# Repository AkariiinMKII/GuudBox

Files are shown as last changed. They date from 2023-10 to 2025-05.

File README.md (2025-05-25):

# GuudBox

GuudBox uses GP2040-CE firmware with custom key maps and layouts, here's related links you may need:

[GP2040-CE GitHub page](https://github.com/OpenStickCommunity/GP2040-CE) | [GP2040-CE documentation](https://gp2040-ce.info/introduction)

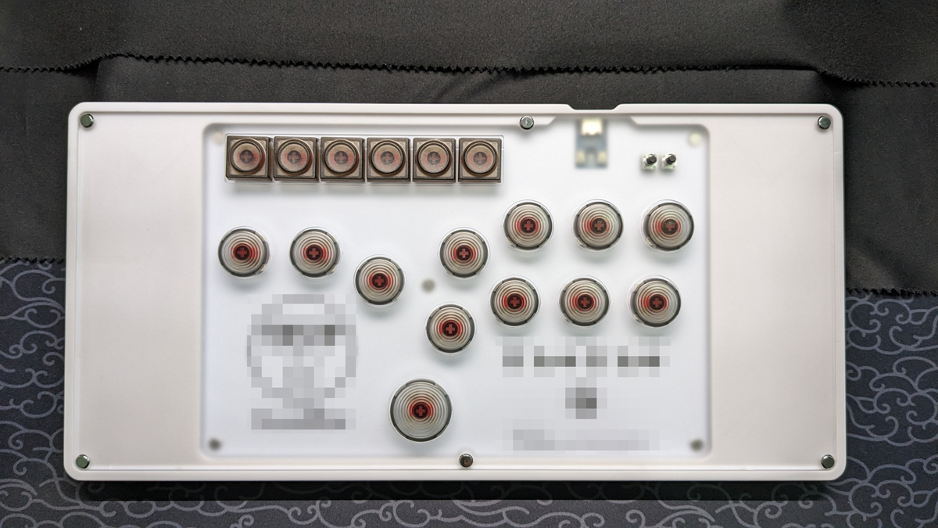
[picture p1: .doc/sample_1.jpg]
Sample

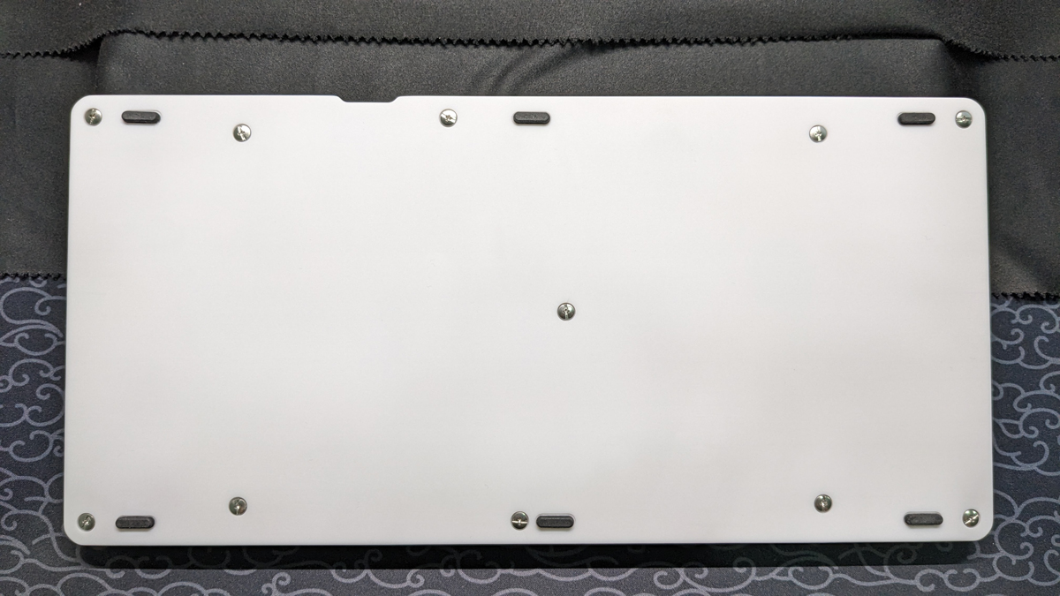
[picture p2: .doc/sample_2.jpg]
Sample

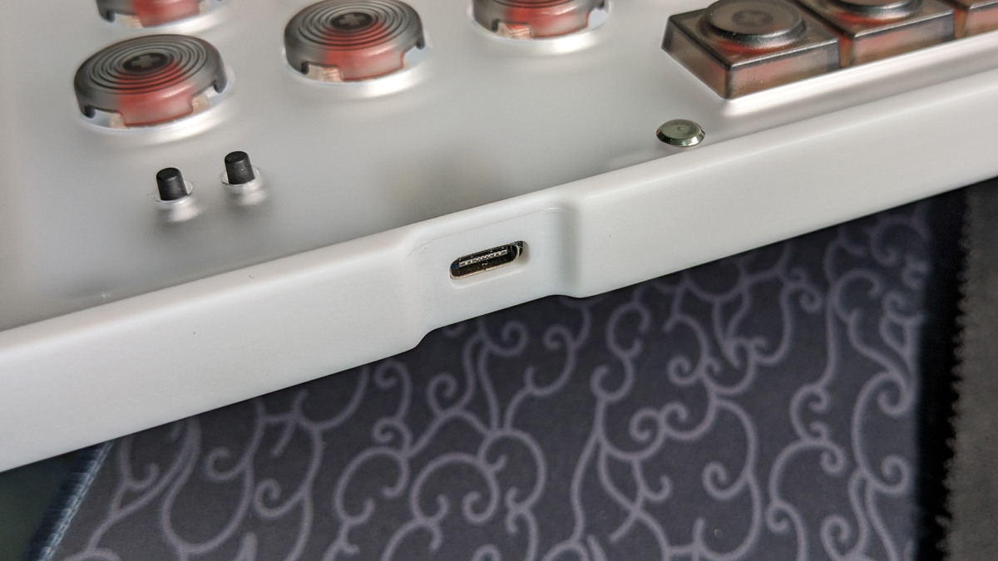
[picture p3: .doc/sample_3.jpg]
Sample


## Hardwares

__Screwdrivers and soldering iron are necessary to build this device!__

__Screwdrivers and soldering iron are necessary to build this device!__

__Screwdrivers and soldering iron are necessary to build this device!__

### Standard parts

_Parts you need to purchase. All of these should be available in China Mainland._

__Make sure you can get these parts (or compatible ones) before building!__

| Parts | Quantity | Shopping links for reference |
| --- | --- | --- |
| Waveshare RP2040-Zero | 1 | |
| Gateron low profile switches v2.0 | 18 | |
| Gateron low profile hotswap connectors  | 18 | |
| 21mm MX switch compatible round keycaps | 12 | [PUNK WORKSHOP](https://item.taobao.com/item.htm?id=684778888971) |
| 26mm MX switch compatible round keycaps | 1 | [PUNK WORKSHOP](https://item.taobao.com/item.htm?id=684778888971) |
| Standard MX switch keycaps | 6 | [DEADLINE DOYS](https://item.taobao.com/item.htm?id=705145796401) |
| 6x6x10mm push button switches | 2 | [LCSC](https://item.szlcsc.com/580446.html) |
| M3*13 locking screws | 6 | [Taobao](https://detail.tmall.com/item.htm?id=714800474141) |
| M3*5 locking screws | 5 | [Taobao](https://detail.tmall.com/item.htm?id=714800474141) |
| 13x4mm round head silicone foot pads* | 6 | [Taobao](https://item.taobao.com/item.htm?id=579251575258) |

_*: Thickness should be greater than 0.5mm._

### Custom parts

| Parts | Quantity | Related files | Remarks |
| --- | --- | --- | --- |
| Controller PCB | 1 | [Gerber_GuudBox.zip](PCB/Gerber_GuudBox.zip) | 1.6mm thick |
| CNC / 3D printed bottom case | 1 | [Bottom Case.STEP (for CNC)](Case/Bottom%20Case.STEP) / [Bottom Case.STL (for 3D printing)](Case/Bottom%20Case.STL) | |
| CNC / laser cutted cover plate* | 1 | [Cover Plate.STEP (for CNC)](Case/Cover%20Plate.STEP) / [Cover Plate.dxf (for laser cutting)](Case/Cover%20Plate.dxf) | 3mm thick |

_*: If you'd like to replace 21mm round keycaps with 26mm ones, use files in [Alternative](/Case/Alternative) folder for cover plate._

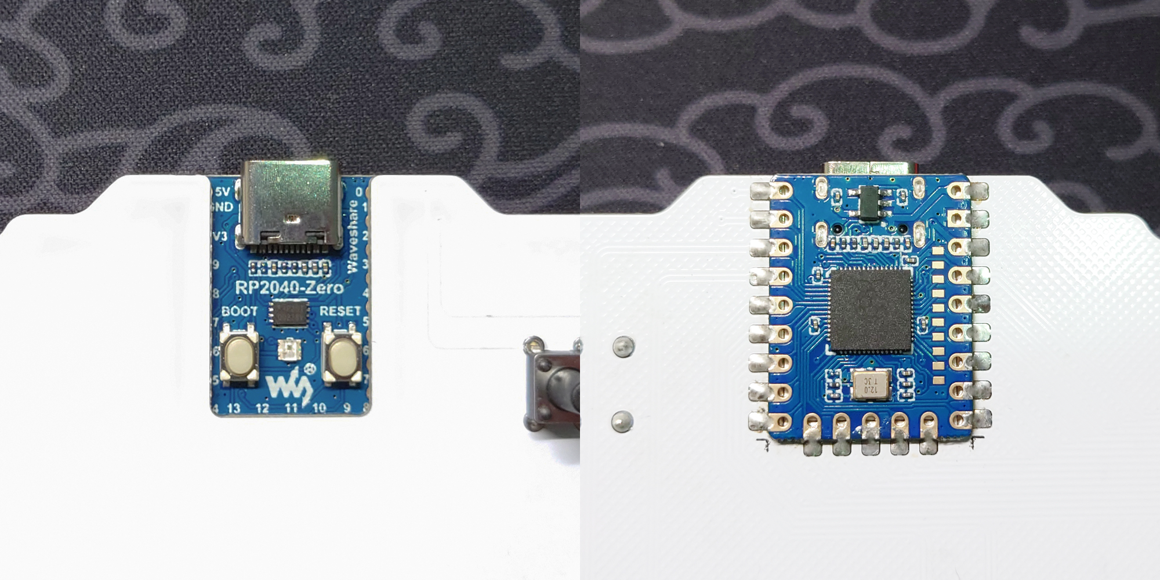
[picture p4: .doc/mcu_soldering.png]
MCU Soldering


_The RP2040-Zero MCU board should be soldered on __bottom side__ of the controller PCB with __front side up__. Make the position as accurate as possible to avoid conflicts with case._

### Accessories

#### Wrist Rest

- For CNC

| Parts | Quantity | Related files / links |
| --- | --- | --- |
| CNC wrist rest | 1 | [Wrist Rest_CNC_low_profile.STEP](Accessories/Wrist%20Rest_CNC_low_profile.STEP) |
| 20x3mm round head silicone foot pads* | 4 | [Taobao](https://item.taobao.com/item.htm?id=579128426494) |

_*: Thickness should be greater than 1mm._

- For 3D printing

| Parts | Quantity | Related files / links | Remarks |
| --- | --- | --- | --- |
| 3D printed wrist rest base part | 1 | [Wrist Rest_3Dp_base_low_profile.STL](Accessories/Wrist%20Rest_3Dp_base_low_profile.STL) | |
| Laser cutted cover plate | 1 | [Wrist Rest_3Dp_cover.dxf](Accessories/Wrist%20Rest_3Dp_cover.dxf) | 3mm thick |
| 20x3mm round head silicone foot pads* | 8 | [Taobao](https://item.taobao.com/item.htm?id=579128426494) | |

_*: Thickness should be greater than 1mm._

Here's a sample of 3D printed wrist rest:

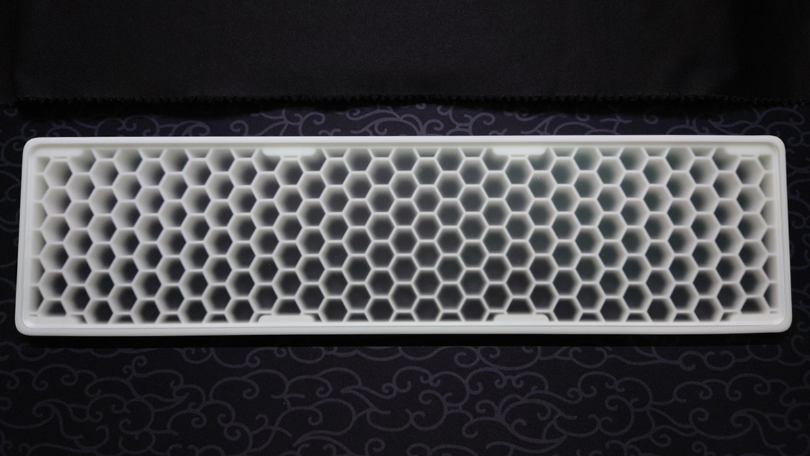
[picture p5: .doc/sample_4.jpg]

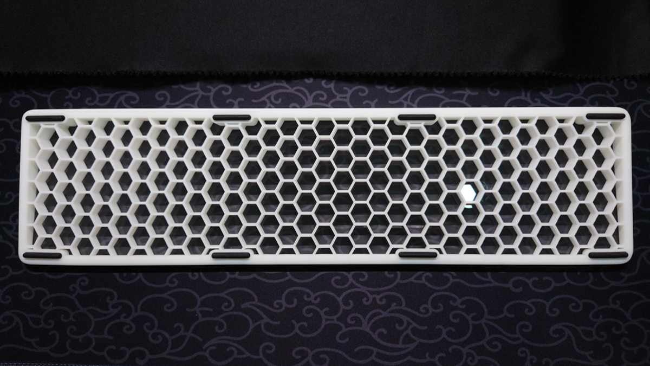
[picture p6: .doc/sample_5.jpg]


### Customizations

Use files in [Misc](/Misc).

[EasyEDA Pro](https://pro.easyeda.com/editor) is needed to edit `.epro` file.

## Softwares

Firmwares are modified and compiled in [AkariiinMKII/GuudBox-GP2040-CE](https://github.com/AkariiinMKII/GuudBox-GP2040-CE).

### Firmware Installation

1. Download the firmware (.uf2 file) in [release page](https://github.com/AkariiinMKII/GuudBox/releases).
2. Hold `BOOT` buttom on MCU board when plugging your controller into a PC. A new removable drive named `RPI-RP2` should appear in your file explorer.
3. Drag and drop the firmware into the removable drive.
4. Wait for the device to automatically disconnect.

### Key Maps

_Default key map in firmware, you can change it in [GPIO Pin Mapping](https://gp2040-ce.info/web-configurator/menu-pages/gpio-pin-mapping) settings._

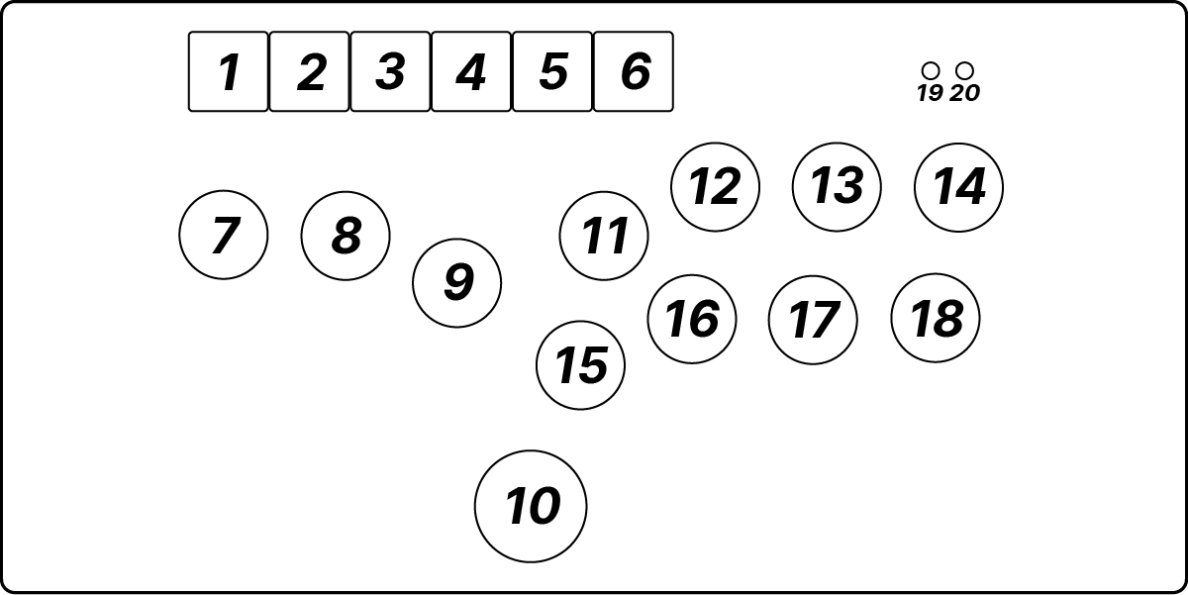
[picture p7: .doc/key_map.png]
Key Map


| Position | GPIO Pin | GP2040-CE  | XInput | Switch  | PS4 | PS3 | DirectInput  | Arcade |
| --- | --- | --- | --- | --- | --- | --- | --- | --- |
| 1 | 14 | L3 | LS | LS | L3 | L3 | 11 | LS |
| 2 | 15 | R3 | RS | RS | R3 | R3 | 12 | RS |
| 3 | 26 | A1 | Guide  | Home | PS | PS | 13 | Home |
| 4 | 27 | A2 | - | Capture | Touchpad | - | 14 | - |
| 5 | 28 | S1 | Back | Minus | Share | Select | 9 | Coin |
| 6 | 29 | S2 | Start  | Plus | Options | Start | 10 | Start  |
| 7 | 13 | LEFT | LEFT | LEFT | LEFT | LEFT | LEFT | LEFT |
| 8 | 12 | DOWN | DOWN | DOWN | DOWN | DOWN | DOWN | DOWN |
| 9 | 11 | RIGHT | RIGHT  | RIGHT | RIGHT | RIGHT | RIGHT | RIGHT  |
| 10 | 10 | UP | UP | UP | UP | UP | UP | UP |
| 11 | 8 | B3 | X | Y | Square | Square | 1 | P1 |
| 12 | 6 | B4 | Y | X | Triangle | Triangle | 4 | P2 |
| 13 | 4 | R1 | RB | R | R1 | R1 | 6 | P3 |
| 14 | 2 | L1 | LB | L | L1 | L1 | 5 | P4 |
| 15 | 9 | B1 | A | B | Cross | Cross | 2 | K1 |
| 16 | 7 | B2 | B | A | Circle | Circle | 3 | K2 |
| 17 | 5 | R2 | RT | ZR | R2 | R2 | 8 | K3 |
| 18 | 3 | L2 | LT | ZL | L2 | L2 | 7 | K4 |
| 19* | 0 | Fn | Fn | Fn | Fn | Fn | Fn | Fn |
| 20** | 1 | Turbo | Turbo  | Turbo | Turbo | Turbo | Turbo | Turbo  |

_*: Disabled by default, enable the function in [Hotkey](https://gp2040-ce.info/web-configurator/menu-pages/settings#hotkey-settings) settings._

_**: Disabled by default, enable the function in [Turbo](https://gp2040-ce.info/add-ons/turbo) settings._

### Configurations

Hold `S2` (position 6 in default key map) when plugging your controller into a PC, and then visit <http://192.168.7.1> in a web browser to access the Web Configurator.

It is strongly recommended to read the [documentation](https://gp2040-ce.info/web-configurator/) before using the configurator.

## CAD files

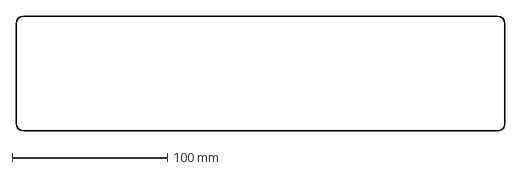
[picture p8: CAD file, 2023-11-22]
Accessories/Wrist Rest_3Dp_cover.dxf
315.1 x 74.1 mm

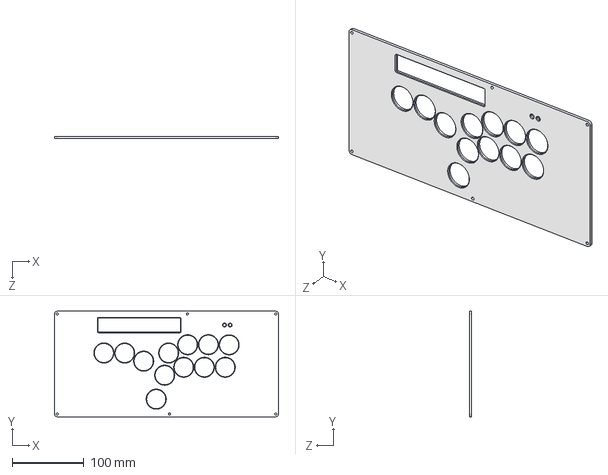
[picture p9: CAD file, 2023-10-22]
Case/Alternative/Cover Plate_all26.STEP
313.2 x 147.6 x 3.00 mm

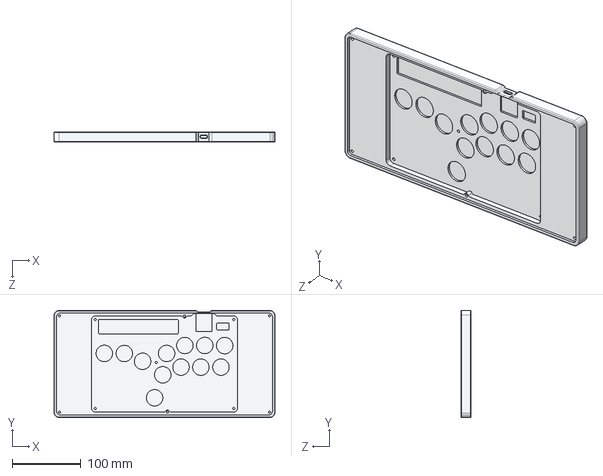
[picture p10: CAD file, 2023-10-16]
Case/Bottom Case.STEP
321.6 x 156.0 x 15.1 mm

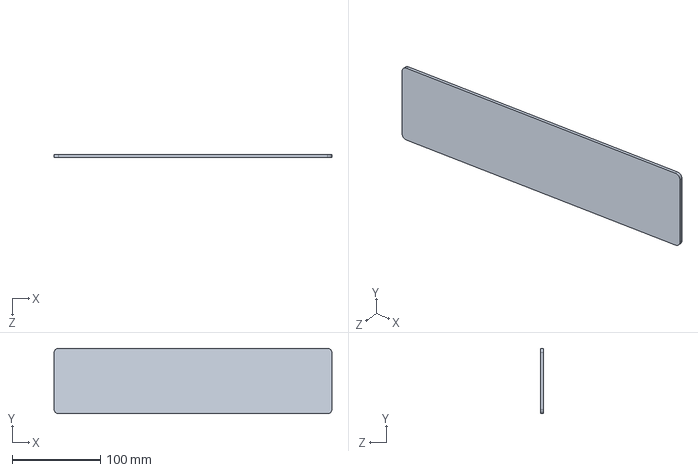
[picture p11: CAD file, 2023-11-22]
Misc/Wrist Rest_3Dp_cover.SLDPRT
315.1 x 74.1 x 3.00 mm

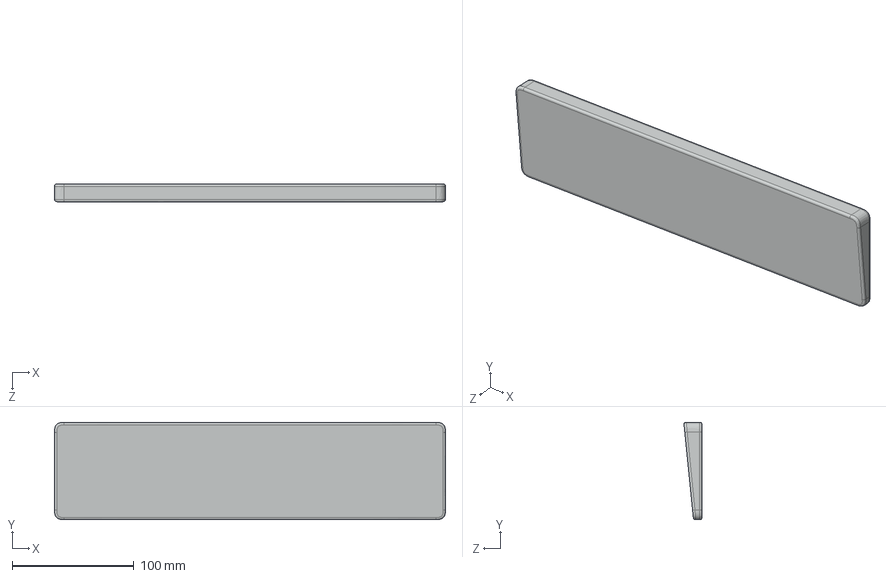
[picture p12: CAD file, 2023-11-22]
Accessories/Wrist Rest_CNC_low_profile.STEP
321.6 x 80.0 x 14.8 mm

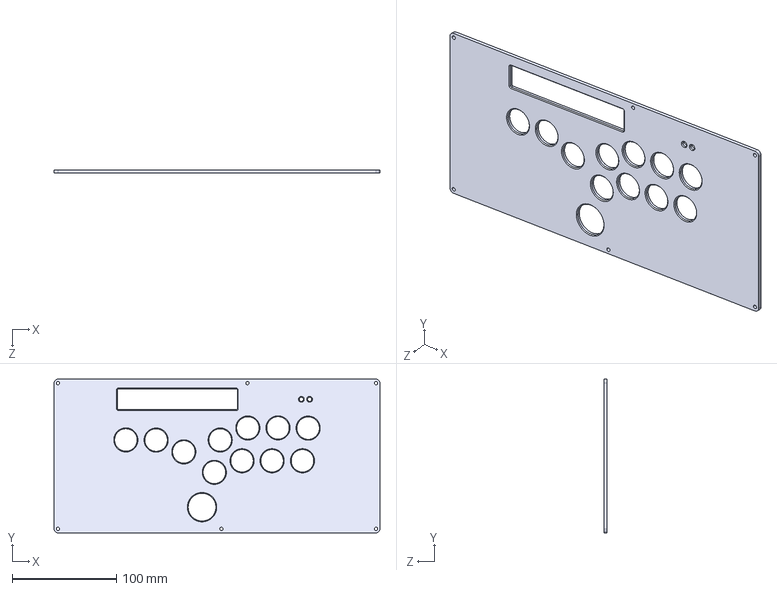
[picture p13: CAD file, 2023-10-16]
Case/Cover Plate.STEP
313.2 x 147.6 x 3.00 mm

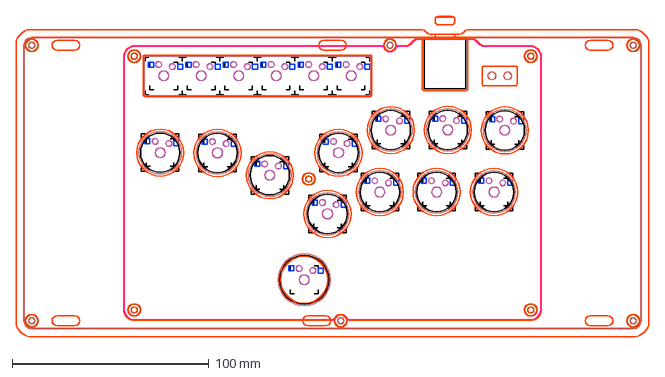
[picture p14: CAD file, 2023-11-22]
Misc/GuudBox.dxf
321.6 x 162.6 mm

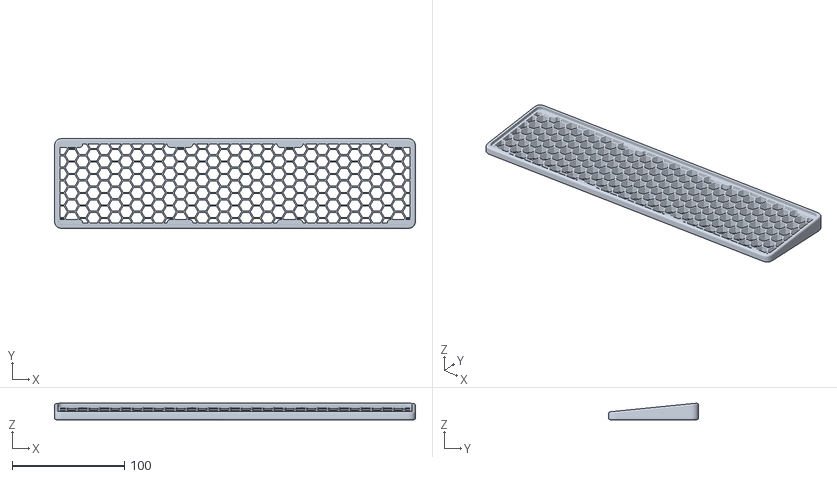
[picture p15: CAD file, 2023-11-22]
Accessories/Wrist Rest_3Dp_base_low_profile.STL
321.6 x 80.0 x 14.8

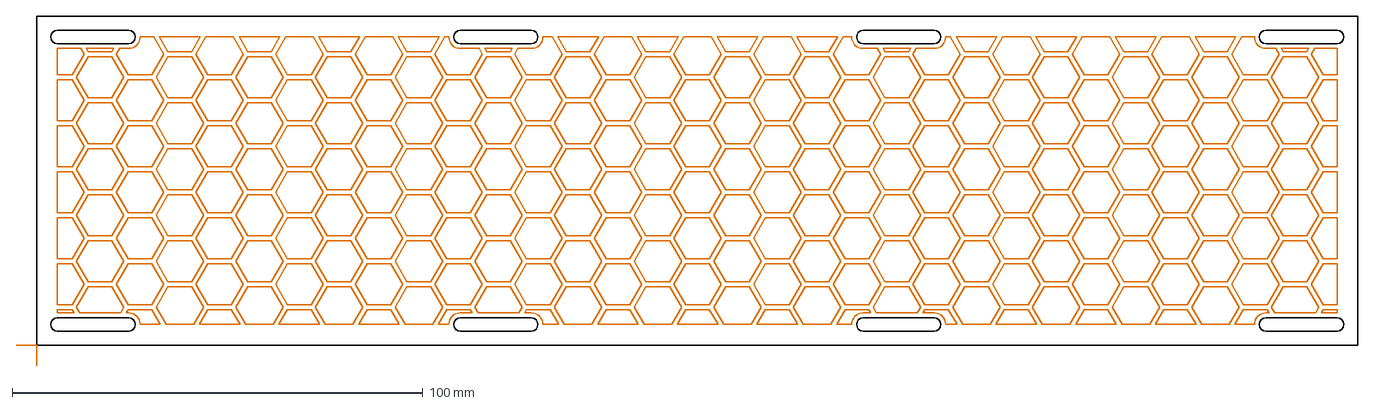
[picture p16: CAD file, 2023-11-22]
Misc/Wrist Rest_3Dp_base.dxf
326.6 x 85.0 mm

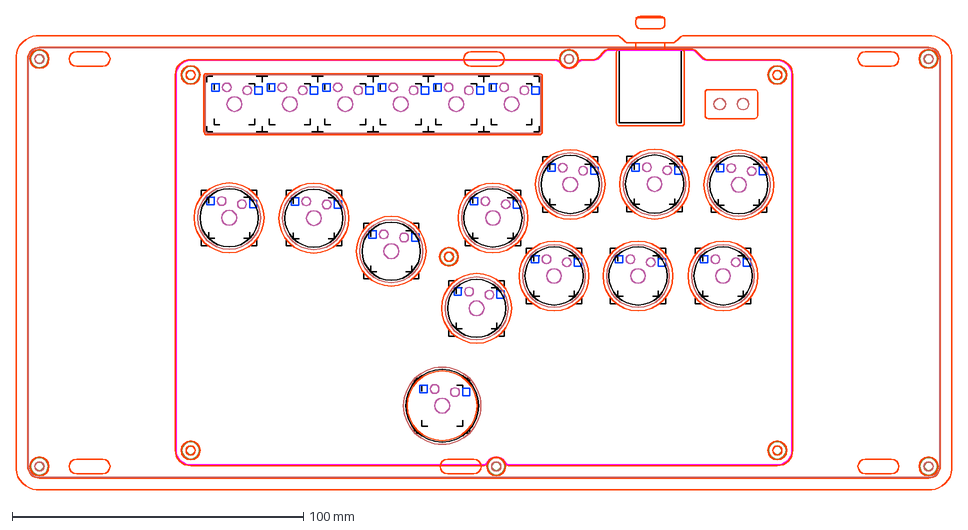
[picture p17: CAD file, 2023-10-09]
Misc/GuudBox Draft.dxf
321.6 x 162.6 mm

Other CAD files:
Misc/Bottom Case.SLDPRT
Misc/Wrist Rest_3Dp_base_low_profile.SLDPRT
Misc/Wrist Rest_CNC_low_profile.SLDPRT
Misc/Cover Plate_all26.SLDPRT
Misc/Cover Plate.SLDPRT
Case/Alternative/Cover Plate_all26.dxf
Case/Bottom Case.STL
Case/Cover Plate.dxf

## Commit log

2023-10-09 Add case files
    [Bottom Case.STEP, Bottom Case.STL, Cover Frame.STEP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]
2023-10-16 Update files
    [Bottom Case.STEP, Bottom Case.STL, Cover Frame.STEP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]
2023-10-16 Update files and pages
    [Cover Frame.STL, Cover Plate.STEP, Cover Plate.dxf]
2023-11-22 Update files and documentations for wrist rest
    [Bottom Case.SLDPRT, Cover Plate.SLDPRT, Cover Plate_all26.SLDPRT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]
